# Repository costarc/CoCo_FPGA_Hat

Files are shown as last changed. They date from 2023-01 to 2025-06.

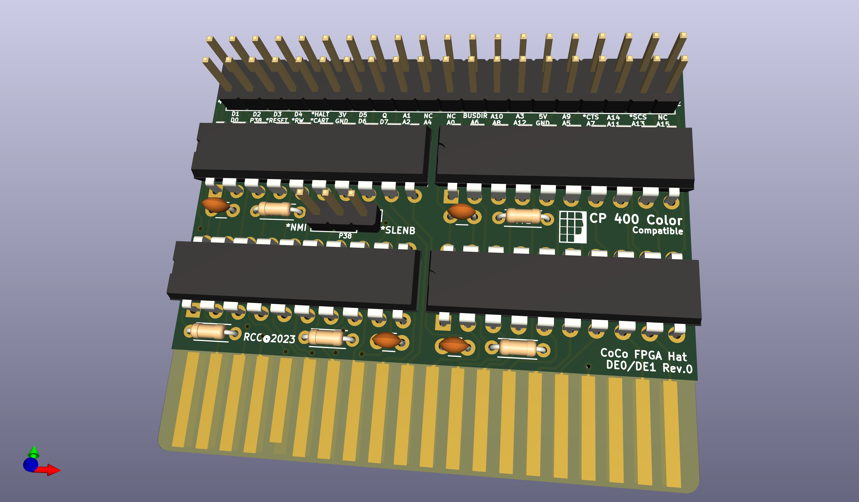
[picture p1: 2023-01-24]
Hardware Interface/CoCo_FPGA_Hat.png

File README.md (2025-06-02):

# CoCo_FPGA_Hat
A Cartridge interface that converts TRS-Color 5v signal levels in the bus to 3.3v, exposed over an IDC connector for external devices that operates at 3.3v level.

Even though this project was developed and tested with FPGA development boards Terasic DE0 and DE1, the interface can actually interface with any 3.3v device, even microcontrollers, to implement peripherals for the TRS-80 Color computer.

This project as adapted from my MSX DE1 hat for DE1 (https://github.com/costarc/MSX_FPGA_Hat).

Project Status: RIP. Project was assembled and tested, proven to work. Sample test project is available in the folder Reference Designs, which demonstrate how to implement a Cartridge ROM using the interface and a connected Terasic DE0.

Because it was not extensively tested and no other designs developed, there might be limitations on which functions it might be able to implement, therefore build at your own risk! :)

# Technical Description of the Interface
The interface connects the computer BUS to the FPGA GPIOs, using the flat cable.
The interface should be connected to JP2 of DE1, which corresponds to GPIO_1. This is the GPIO used in all the reference designs in this project. To use JP1 (GPIO_0), all pins must be remapped for the projects.

Address and control signals always flow from the computer to the FPGA - the DIR and /OE signals in U2,U3,U4 and U5 are always asserted (pull-up for bus directoin (Pin 1) and grounded for /OE (pin 19).

For U1, the BUS direction is controlled by the computer read signal (RD_n) in MSX. When read operation is triggered (RD_n = 0), the directon of the data in U1 flows from the FPGA to the computer. At all other times, the data flows from the computer to the FPGA.

U1 has a pull-up in the /OE pin, to keep any output disabled until the FPGA drives this pin low, which should only occur when the FPGA is in fact requested by the computer. Keeping /OE high isolates the computer BUS from anythign happening in the FPGA, which is also important during the boot in the computer.

# Controlling Flow of Data in the Interface
The recommended method to drive the interace signals is as follows:

U1 bus direction (pin 1): no additional implementaton is required - this pin is controlled automatically by the computer according his operations. For example, when the CoCo computer is requesting data from the FPGA, this pin is asserted HIGH by *R/W = 1, when sending data it is asserted LOW because *R/W = 0.
Note that the FPGA pins are connected on the bus A of U1, and CoCo bus is connected in the bus B of U1 - this allowed both keep the CIs all aligned in the same direction and use the CoCo *R/W signal to drive the directon of this bus).

U1 /OE (Output Enable, pin 19): This pin should be put in LOW whenever the FPGA detects that it is being requested - for example, if a ROM is implemented in the FPGA, the address and slot decoding should detect and assert according the GPIO pin /C_U1_D_OE (name was meant to stand for "CI U1, computer Data bus, pin OE).

U2,U3,U4,U5 bus direction: also no need to be concerned - these CIs have fixed bus direction, and constantly asserted HIGH for data to flow from the 74lvc245 bus A to bus B. 
The interface has some pins being used to carry data from the FPG to the computer in these CIs, in which case the routing for such signals was made bringing in input from the GPIO to the bus A, and teh exit in the bus B reouted to the computer.

# Jumpers and Configurations

The limited number of GPIOs in the development board require that we do some compromises in the design.
Some of the less used signals were routed to jumpers, at which point they can be selected to be sent to the FPGA.

J1 allow to select one of *SLENB OR *NMI to B be connected to FPGA connector pin 39 (/C_NMI_SLENB).

# SRAM Addon
Because some development boards (such as Terasic DE0) does not have a SRAM module, it makes it difficult to implement RAM cores due to DDRAM complexity.
For this reason, I designed also a SRAM addon to plug to the DE0  GPIO. This design in in the folder "DE0_Addon_Board".

# Other Important Considerations

The interface was designed to be compatible with Terasic DEn series of boards. However, these boards present some differences in the GPIOs funtionalities, where some bords (like DE1) have 36 generic I/O pins avaialable fo rinput/output functions, and others like DE0 have four pins dedicated to either input or outputs. This is the case of pins 1 and 3, whch are input only pins, and 19, 21 which are output only.
These differences were already considered in the reference designs, and these pins assigned to functions that will not case problems of limitations to the designs.
If you want to change the pin mapping in the FPGA designs, pay attention to these pins - do not assign functions opposite to the directon they actually work.

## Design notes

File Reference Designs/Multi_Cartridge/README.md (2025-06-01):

Design: Multi_Cartridge

Function: Demonstrate how to implement a game cartridge using the CoCo_FPGA_Hat.

The following two sample desings are implemented using an Terasic DE1 development board.
 1. Implement a ROM using the Flashram in the FPGA development board
 2. Implement a ROM using the internal FPGA BlockRAM

Quick Start Guide
-----------------

1. Connect everything and turn on the DE board
2. Program the DE board with the .sof file
3. Move SW9 to UP position, and SW8 Down
4. Switch on the computer - should boot the game stored in the Flash RAM
5. Switch off the computer
6. Move SW9 to Down position, and SW8 UP
7. Switch on the computer - should boot the game stored in the BlockROM

Build Yourself
--------------
1. Using the Altera Control Panel, write a 8KB, 16KB or 32KB ROM game to the FLASH RAM (starting at address 0)
2. Use rom_to_vhd.py program (in the Tools directory) to convert a ROM to VHDL:
   cd Tools
   python rom_to_vhd.py GALAGA.ROM > rom.vhdl
3. Build the project
4. Program the .sof file to the board

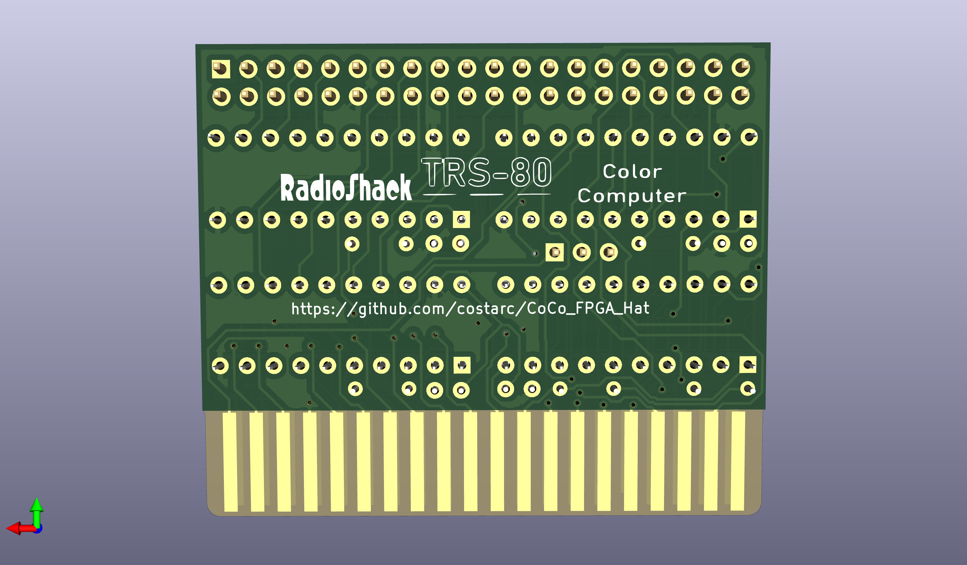
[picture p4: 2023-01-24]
Hardware Interface/CoCo_FPGA_Hatb.png

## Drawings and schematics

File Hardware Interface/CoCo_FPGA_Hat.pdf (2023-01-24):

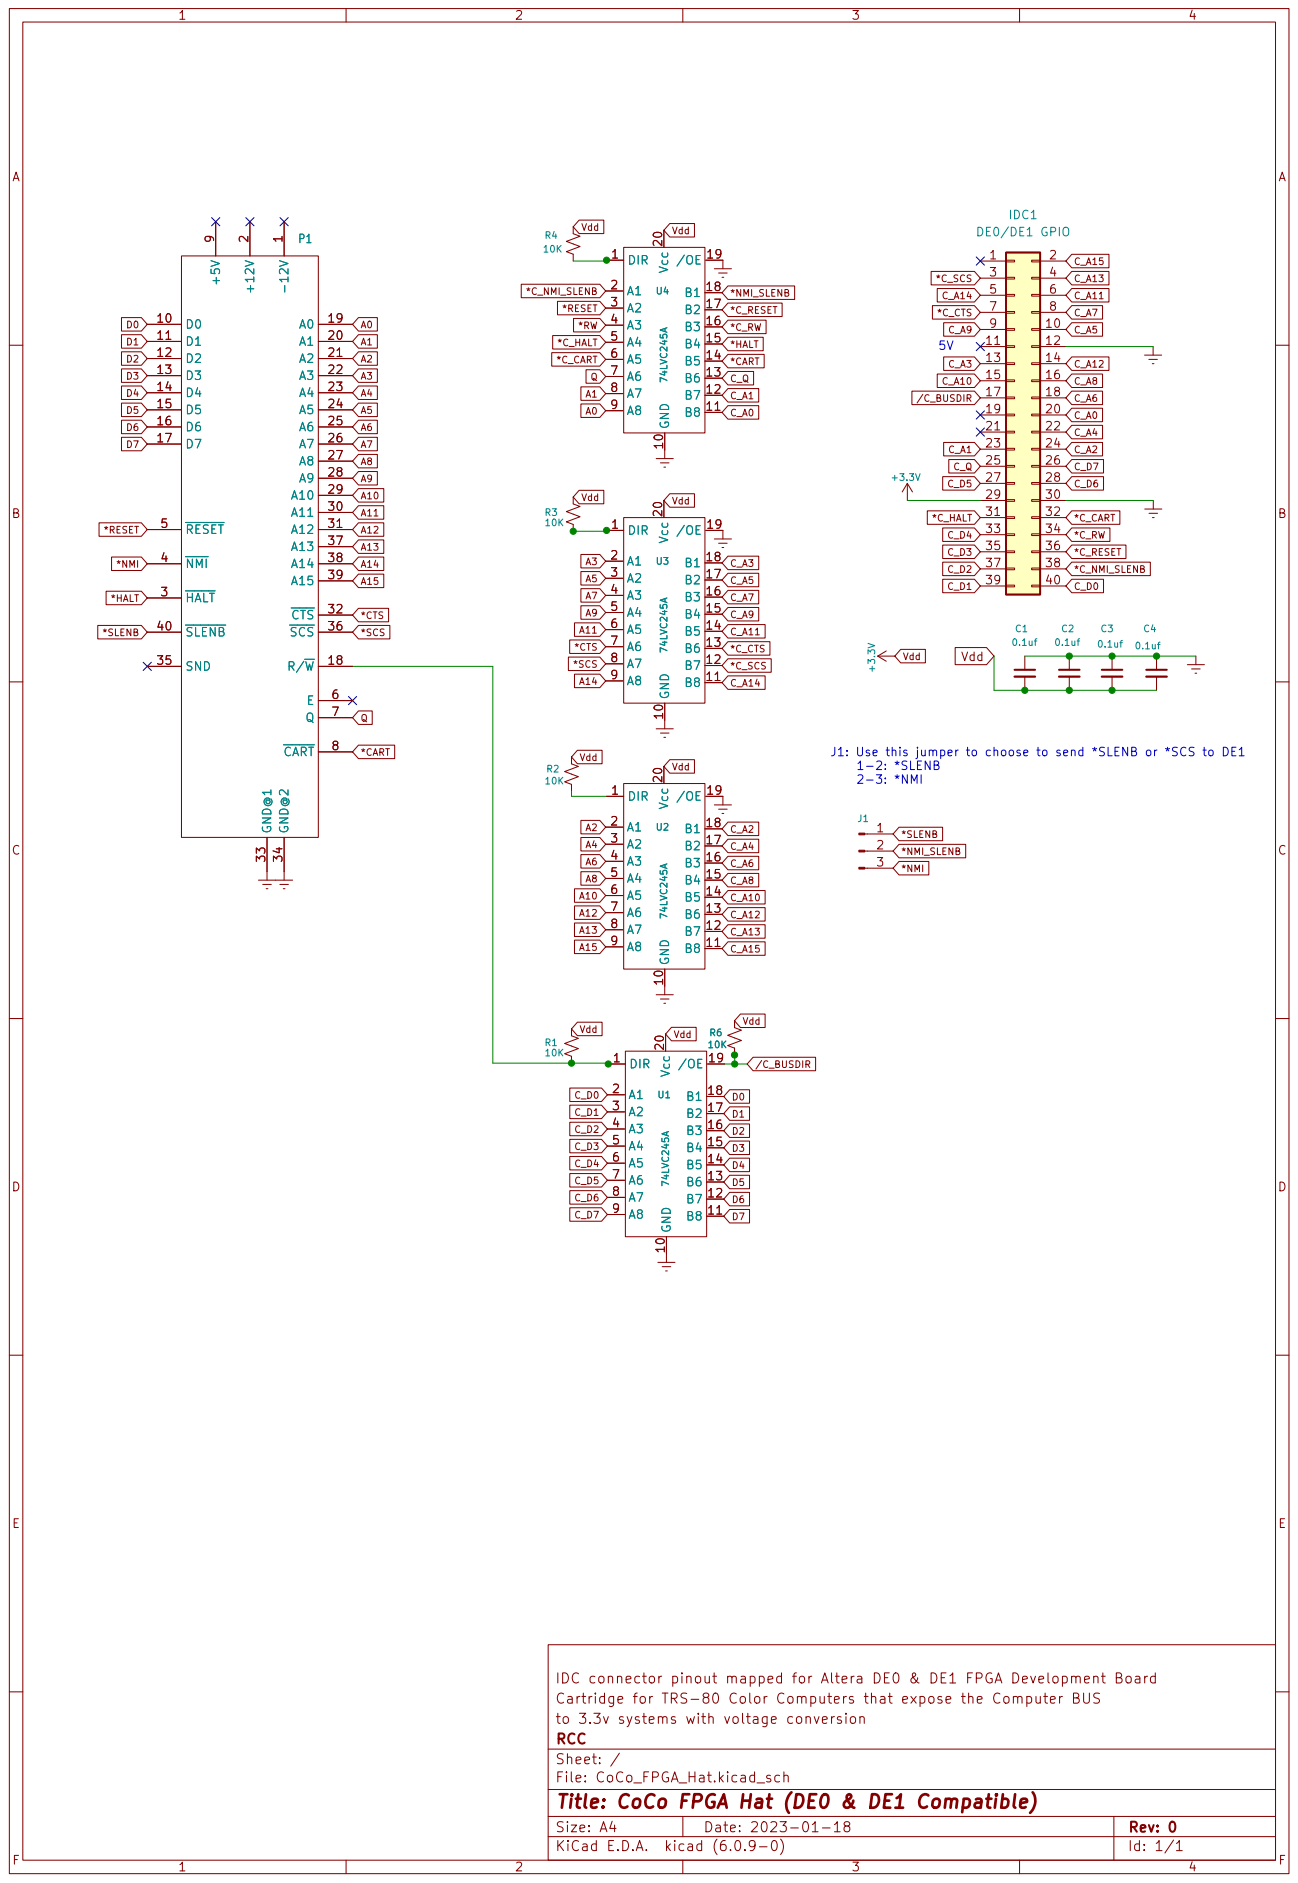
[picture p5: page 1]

2 A1 20 A2 21 A3 22 A4 23 A5 24 A6 25 A7 26 A8 27 A9 28 A10 29 ~{HALT} 3 A11 30 A12 31 ~{CTS} 32 GND@1 33 GND@2 34 SND 35 ~{SCS} 36 A13 37 A14 38 A15 39 ~{NMI} 4 ~{SLENB} 40 ~{RESET} 5 E

J1: Use this jumper to choose to send *SLENB or *SCS to DE1
1-2: *SLENB

IDC connector pinout mapped for Altera DE0 & DE1 FPGA Development Board
Cartridge for TRS-80 Color Computers that expose the Computer BUS
to 3.3v systems with voltage conversion
File: CoCo_FPGA_Hat.kicad_sch Sheet: / RCC

Id: 1/1 Title: CoCo FPGA Hat (DE0 & DE1 Compatible)

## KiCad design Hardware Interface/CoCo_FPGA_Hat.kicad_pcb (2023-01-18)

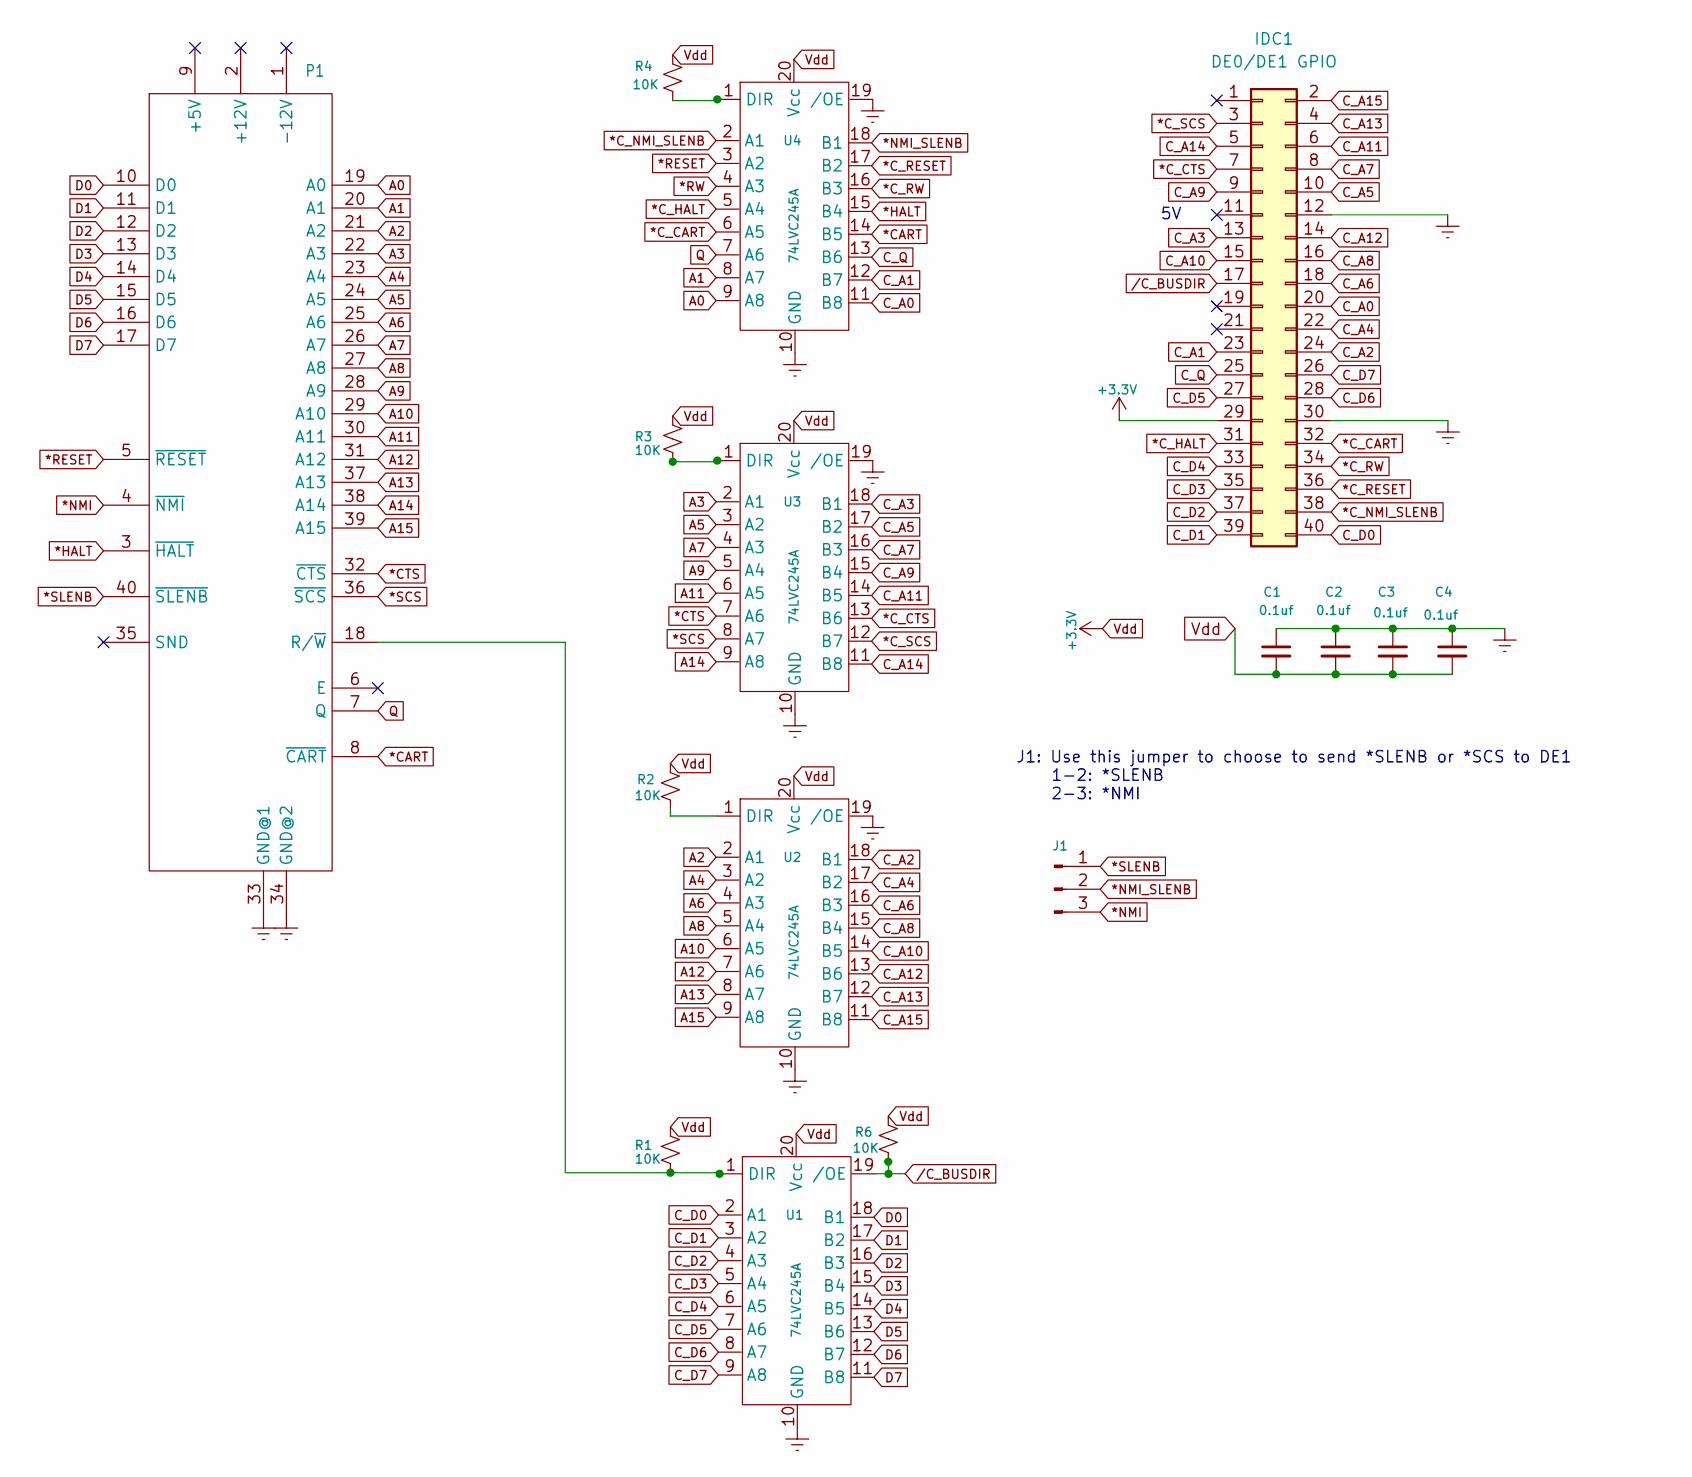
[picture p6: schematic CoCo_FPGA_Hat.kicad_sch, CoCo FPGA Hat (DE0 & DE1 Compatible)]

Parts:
C1, C2, C3, C4: 0.1uf; C_Disc_D3.0mm_W1.6mm_P2.50mm
IDC1: DE0/DE1 GPIO; PinHeader_2x20_P2.54mm_Vertical
J1: J1; PinHeader_1x03_P2.54mm_Vertical
P1: CoCo_Slot; COCO-CART-2.1X1.75
R1, R2, R3, R4, R6: 10K; R_Axial_DIN0204_L3.6mm_D1.6mm_P5.08mm_Horizontal
U1, U2, U3, U4: 74LVC245A; DIP-20_W7.62mm

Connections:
*CART: P1.8 (~CART), U4.14 (B5)
*CTS: P1.32 (~CTS), U3.7 (A6)
*C_CART: IDC1.32, U4.6 (A5)
*C_CTS: IDC1.7, U3.13 (B6)
*C_HALT: IDC1.31, U4.5 (A4)
*C_NMI_SLENB: IDC1.38, U4.2 (A1)
*C_RESET: IDC1.36, U4.17 (B2)
*C_RW: IDC1.34, U4.16 (B3)
*C_SCS: IDC1.3, U3.12 (B7)
*HALT: P1.3 (~HALT), U4.15 (B4)
*NMI: J1.3, P1.4 (~NMI)
*NMI_SLENB: J1.2, U4.18 (B1)
*RESET: P1.5 (~RESET), U4.3 (A2)
*RW: U4.4 (A3)
*SCS: P1.36 (~SCS), U3.8 (A7)
*SLENB: J1.1, P1.40 (~SLENB)
+5V: P1.9 (+5V)
A0: P1.19 (A0), U4.9 (A8)
A1: P1.20 (A1), U4.8 (A7)
A2: P1.21 (A2), U2.2 (A1)
A3: P1.22 (A3), U3.2 (A1)
A4: P1.23 (A4), U2.3 (A2)
A5: P1.24 (A5), U3.3 (A2)
A6: P1.25 (A6), U2.4 (A3)
A7: P1.26 (A7), U3.4 (A3)
A8: P1.27 (A8), U2.5 (A4)
A9: P1.28 (A9), U3.5 (A4)
A10: P1.29 (A10), U2.6 (A5)
A11: P1.30 (A11), U3.6 (A5)
A12: P1.31 (A12), U2.7 (A6)
A13: P1.37 (A13), U2.8 (A7)
A14: P1.38 (A14), U3.9 (A8)
A15: P1.39 (A15), U2.9 (A8)
C_A0: IDC1.20, U4.11 (B8)
C_A1: IDC1.23, U4.12 (B7)
C_A2: IDC1.24, U2.18 (B1)
C_A3: IDC1.13, U3.18 (B1)
C_A4: IDC1.22, U2.17 (B2)
C_A5: IDC1.10, U3.17 (B2)
C_A6: IDC1.18, U2.16 (B3)
C_A7: IDC1.8, U3.16 (B3)
C_A8: IDC1.16, U2.15 (B4)
C_A9: IDC1.9, U3.15 (B4)
C_A10: IDC1.15, U2.14 (B5)
C_A11: IDC1.6, U3.14 (B5)
C_A12: IDC1.14, U2.13 (B6)
C_A13: IDC1.4, U2.12 (B7)
C_A14: IDC1.5, U3.11 (B8)
C_A15: IDC1.2, U2.11 (B8)
C_D0: IDC1.40, U1.2 (A1)
C_D1: IDC1.39, U1.3 (A2)
C_D2: IDC1.37, U1.4 (A3)
C_D3: IDC1.35, U1.5 (A4)
C_D4: IDC1.33, U1.6 (A5)
C_D5: IDC1.27, U1.7 (A6)
C_D6: IDC1.28, U1.8 (A7)
C_D7: IDC1.26, U1.9 (A8)
C_Q: IDC1.25, U4.13 (B6)
D0: P1.10 (D0), U1.18 (B1)
D1: P1.11 (D1), U1.17 (B2)
D2: P1.12 (D2), U1.16 (B3)
D3: P1.13 (D3), U1.15 (B4)
D4: P1.14 (D4), U1.14 (B5)
D5: P1.15 (D5), U1.13 (B6)
D6: P1.16 (D6), U1.12 (B7)
D7: P1.17 (D7), U1.11 (B8)
GNDREF: C1.1, C2.1, C3.1, C4.1, IDC1.12, IDC1.30, P1.33 (GND@1), P1.34 (GND@2), U1.10 (GND), U2.10 (GND), U2.19 (/OE), U3.10 (GND), U3.19 (/OE), U4.10 (GND), U4.19 (/OE)
unnamed: P1.18 (R/~W), R1.2, U1.1 (DIR)
unnamed: R2.2, U2.1 (DIR)
unnamed: R3.2, U3.1 (DIR)
unnamed: R4.2, U4.1 (DIR)
Q: P1.7 (Q), U4.7 (A6)
Vdd: C1.2, C2.2, C3.2, C4.2, IDC1.29, R1.1, R2.1, R3.1, R4.1, R6.1, U1.20 (Vcc), U2.20 (Vcc), U3.20 (Vcc), U4.20 (Vcc)
/C_BUSDIR: IDC1.17, R6.2, U1.19 (/OE)

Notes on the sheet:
J1: Use this jumper to choose to send *SLENB or *SCS to DE1 1-2: *SLENB 2-3: *NMI

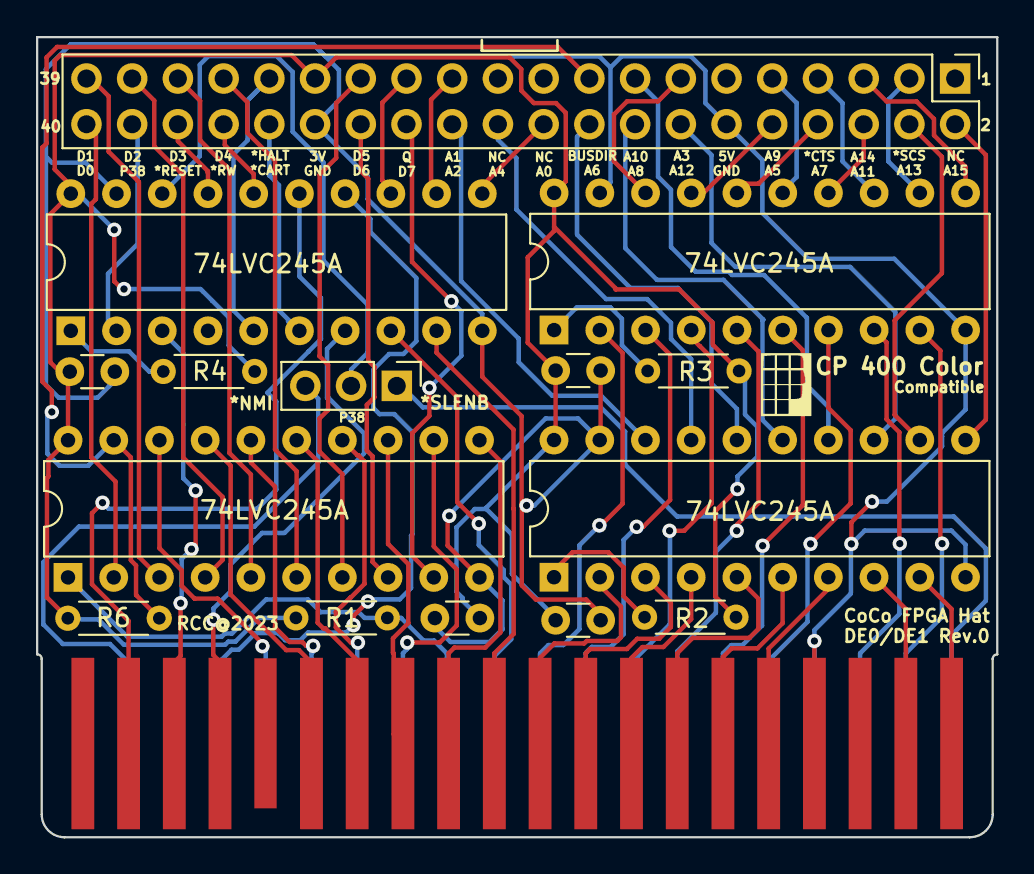
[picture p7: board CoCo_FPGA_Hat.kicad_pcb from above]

Board: 2 copper layers, 53.3 x 44.5 mm, 16 parts (0 on the bottom side), 72 nets.

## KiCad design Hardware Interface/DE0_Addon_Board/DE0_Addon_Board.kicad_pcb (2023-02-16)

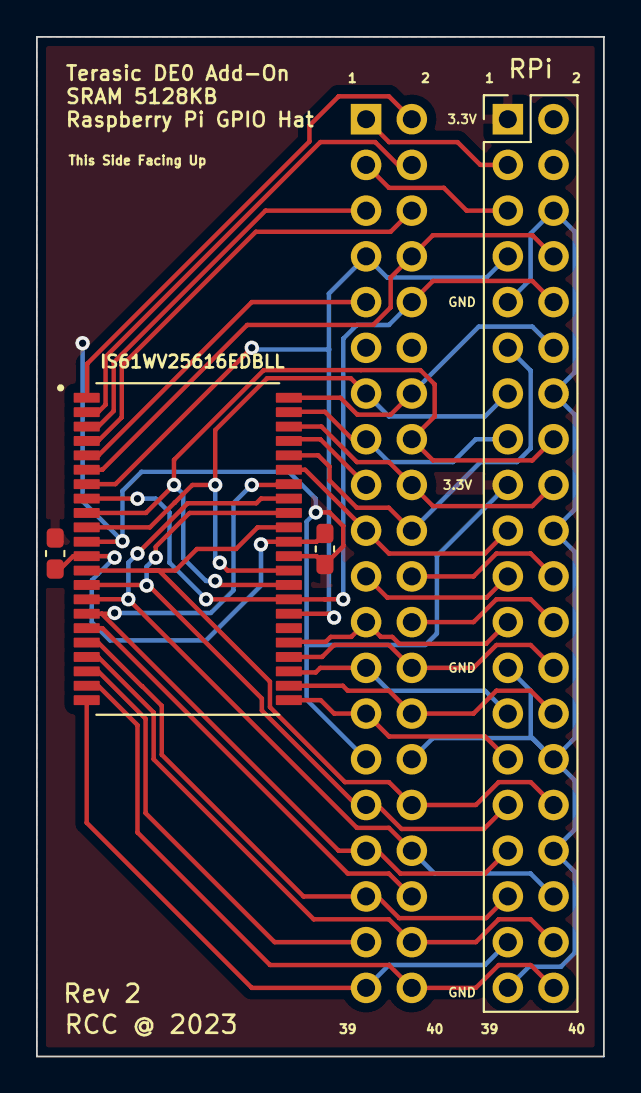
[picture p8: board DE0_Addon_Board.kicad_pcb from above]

Board: 2 copper layers, 31.5 x 56.6 mm, 5 parts (1 on the bottom side), 38 nets.

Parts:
C1, C2: C_Small; C_0603_1608Metric_Pad1.08x0.95mm_HandSolder
J1: DE0/DE1 IDC Connector; PinSocket_2x20_P2.54mm_Vertical
J3: Raspberry Pi Pin Header; PinHeader_2x20_P2.54mm_Vertical
U1: IS61WV25616EDBLL; SOP80P1176X120-44N

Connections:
+3.3V: C1.2, C2.1, J1.29, J3.1, J3.17, U1.11 (VDD), U1.33 (VDD)
A0: J1.2, U1.1 (A0)
A1: J1.4, U1.2 (A1)
A2: J1.5, U1.3 (A2)
A3: J1.6, U1.4 (A3)
A4: J1.9, U1.5 (A4)
A5: J1.35, J3.35, U1.18 (A5)
A6: J1.38, J3.38, U1.19 (A6)
A7: J1.37, U1.20 (A7)
A8: J1.40, J3.40, U1.21 (A8)
A9: J1.39, J3.37, U1.22 (A9)
A10: J1.27, J3.29, U1.23 (A10)
A11: J1.28, J3.28, U1.24 (A11)
A12: J1.25, J3.27, U1.25 (A12)
A13: J1.26, J3.26, U1.26 (A13)
A14: J1.23, J3.23, U1.27 (A14)
A15: J1.18, J3.18, U1.42 (A15)
A16: J1.15, J3.15, U1.43 (A16)
A17: J1.14, J3.12, U1.44 (A17)
BUSDIR_n: J1.8, J3.8, U1.6 (~CE)
D0: J1.7, J3.7, U1.7 (I/O0), U1.29 (I/08)
D1: J1.10, J3.10, U1.8 (I/O1), U1.30 (I/09)
D10: J1.16, J3.16, U1.9 (I/O2), U1.31 (I/10)
D11: J1.13, J3.13, U1.10 (I/O3), U1.32 (I/11)
D12: J1.32, J3.32, U1.13 (I/O4), U1.35 (I/12)
D13: J1.31, J3.31, U1.14 (I/O5), U1.36 (I/13)
D14: J1.34, J3.36, U1.15 (I/O6), U1.37 (I/14)
D15: J1.33, J3.33, U1.16 (I/O7), U1.38 (I/15)
GNDREF: C1.1, C2.2, J1.12, J1.30, J3.6, J3.9, J3.14, J3.20, J3.25, J3.30, J3.34, J3.39, U1.12 (GND), U1.34 (GND)
INT_n: J1.24, J3.24
IORQ_n: J1.19, J3.19, U1.39 (~LB)
M1_n: J1.22, J3.22
OE_n: J1.17, U1.41 (~OE)
P1: J1.1, J3.3
P3: J1.3, J3.5
P21: J1.21, J3.21
P36: J1.36, U1.17 (~WE)
RESET_n: J1.20, J3.11, U1.40 (~UB)

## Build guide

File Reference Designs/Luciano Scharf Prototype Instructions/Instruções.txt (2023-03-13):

[11:06, 22/02/2023] +55 48 8406-2662: Bom dia. Seguem os arquivos contendo os exemplos de loader e bootloader com bank switch.
[11:09, 22/02/2023] +55 48 8406-2662: O último arquivo enviado contem a rom que foi gravada na eeprom, vc poderá testar no emulador de preferência, basta carregar o cartucho GMC e selecionar a rom "final"
[11:10, 22/02/2023] +55 48 8406-2662: mandei as intermediárias ara ficar tranquilo de entender, banco 0 vai o bootloader + loader, banco 1 a tuts1 e banco 2 a tuts2, ao adicionar cada banco completar com zeros até fechar 16384 em cada banco.

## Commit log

2023-01-15 First commit - cloned MSX project as is
    [CoCo_DE1_Hat.kicad_pcb, CoCo_DE1_Hat.kicad_sch]
2023-01-15 Adding PCB layout
    [CoCo_DE1_Hat.kicad_pcb, CoCo_DE1_Hat.kicad_sch]
2023-01-15 Project completd
    [CoCo_DE1_Hat.kicad_pcb, CoCo_DE1_Hat.kicad_sch]
2023-01-15 Small change to silk
    [CoCo_DE1_Hat.kicad_pcb]
2023-01-16 REvised PCB for CoCo, added DE0 version
    [CoCo_FPGA_Hat.kicad_pcb, CoCo_FPGA_Hat.kicad_sch]
2023-01-17 Added gerber files
    [CoCo_FPGA_Hat.kicad_pcb]
2023-01-17 Deleted DE1 design files -> DE0 is compatible with DE1 as well
    [CoCo_FPGA_Hat.kicad_pcb, CoCo_FPGA_Hat.kicad_sch]
2023-01-18 Some updates to revision number and silkscreen
    [CoCo_FPGA_Hat.kicad_pcb, CoCo_FPGA_Hat.kicad_sch]
2023-01-21 Changed directory structure
    [CoCo_FPGA_Hat.kicad_pcb, CoCo_FPGA_Hat.kicad_sch]
2023-01-24 Updated pictures of pcb
2023-01-26 Re-printed the gerbers
    [CoCo_FPGA_Hat-B_Cu.gbr, CoCo_FPGA_Hat-B_Mask.gbr, CoCo_FPGA_Hat-B_Paste.gbr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]
2023-01-26 Added zip file for re-printed gerbers
    [CoCo_FPGA_Hat-B_Cu.gbr, CoCo_FPGA_Hat-B_Mask.gbr, CoCo_FPGA_Hat-B_Paste.gbr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]
2023-01-29 Added project for Add-On board SRAM 512KB for DE0
    [DE0_Addon_Board-B_Cu.gbr, DE0_Addon_Board-B_Mask.gbr, DE0_Addon_Board-B_Paste.gbr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]
2023-01-29 Added 2nd IDC connector in paralell with the SRAM
    [DE0_Addon_Board-B_Cu.gbr, DE0_Addon_Board-B_Mask.gbr, DE0_Addon_Board-B_Paste.gbr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]
2023-01-31 Disclaimer and removed gerber files
    [DE0_Addon_Board-B_Cu.gbr, DE0_Addon_Board-B_Mask.gbr, DE0_Addon_Board-B_Paste.gbr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]
2023-01-31 Renamed signal name for U1 /OE
    [CoCo_FPGA_Hat.kicad_sch]
2023-02-16 Changed footprint of SRAM decoupling capacitors to SMD 0603; Updated SRAM Addon for Rev.2
    [DE0_Addon_Board.kicad_pcb]
